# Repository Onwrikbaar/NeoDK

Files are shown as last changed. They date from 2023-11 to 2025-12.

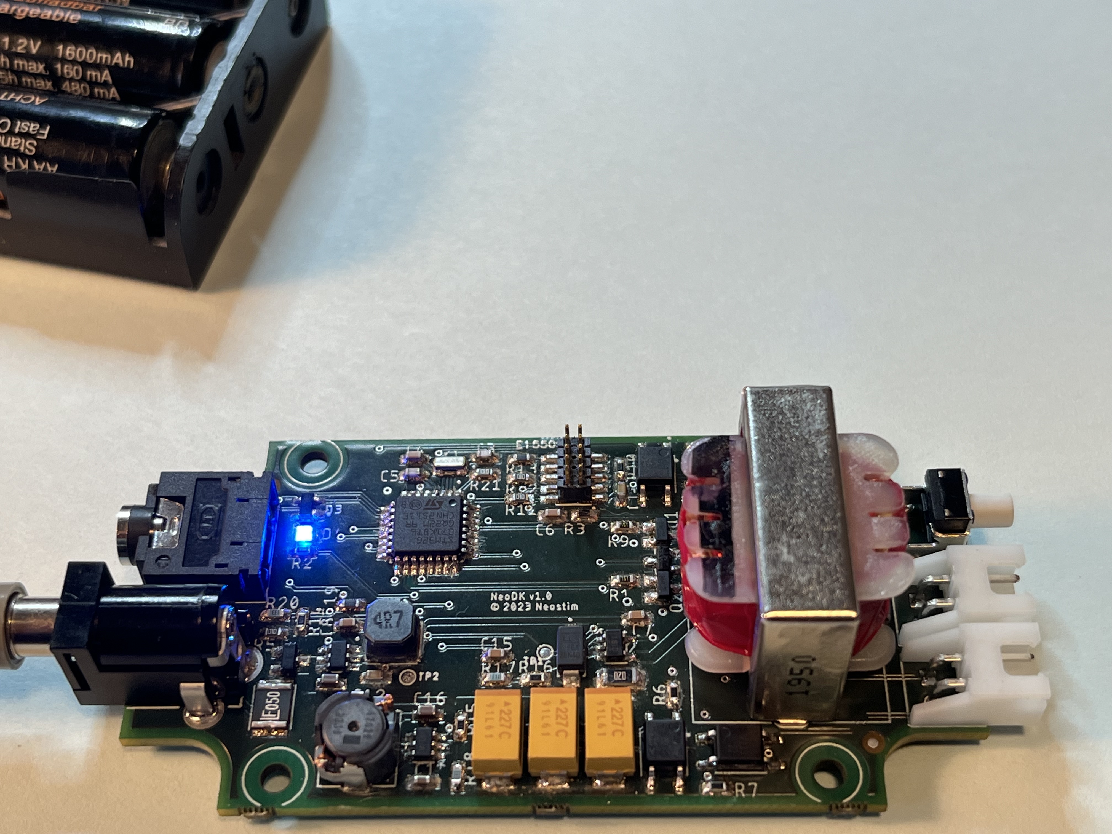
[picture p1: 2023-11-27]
pictures/PopulatedPCB.jpg

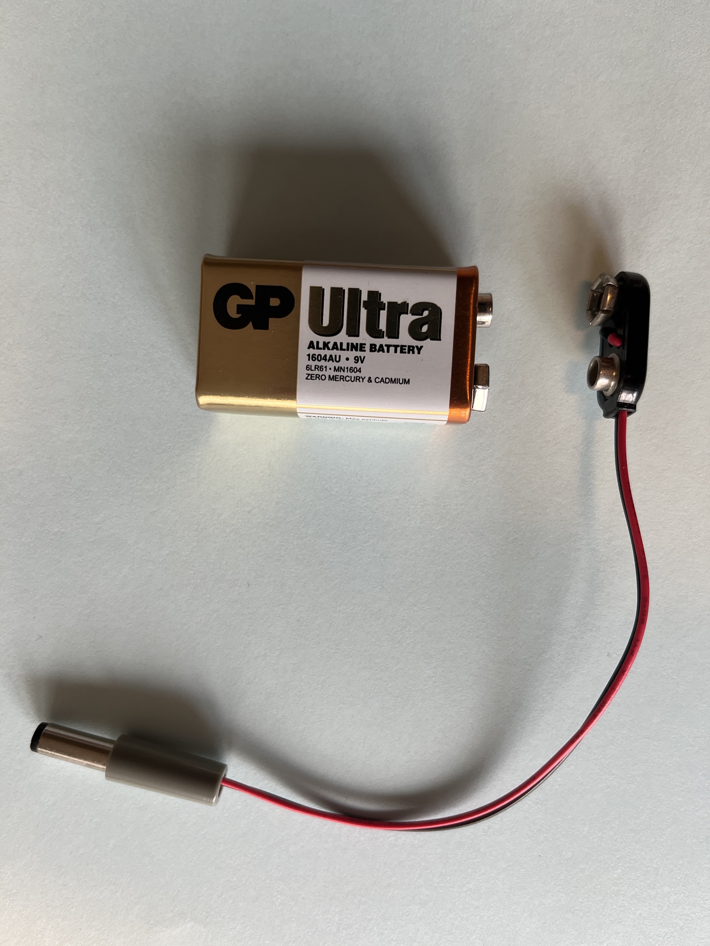
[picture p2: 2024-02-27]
pictures/BatteryCable.jpg

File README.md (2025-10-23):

# NeoDK
Advanced electrostimulation machine development kit.

## Overview
### What is it?
This project describes the design and implementation of a bare-bones, yet highly innovative and powerful, pulse-based electrostimulation device. Both its hardware and its firmware are open for modification and extension.

### Author
Discord: @Onwrikbaar<br/>
E: <onwrikbaar@hotmail.com>

### Status
This is a work in progress. The electronics are production-ready. The firmware is far from finished.

### Goals
1. The last quarter century, innovation in the e-stim realm has been virtually nonexistent, despite massive advances in electronics and cheap computing power. Currently available commercial devices are without exception channel-oriented and produce TENS-style waveforms. Most are horrendously energy-inefficient. The time has come to unlock the potential of a more capable architecture.
2. It is fairly easy for non-programmers to create, share and improve routines to be played on stereostim setups. Currently there is no way to achieve the same for pulse-based e-stim devices. This project aims to (eventually) bridge that gap.

### Disclaimer
NeoDK is experimental, recreational, educational hardware and software. It comes with absolutely no warranty of any kind. Its designs are free to use - under the conditions set forth in its [Licence](LICENSE.txt). Using the designs -in original or modified form- implies acceptance of any and all associated risks and liabilities.

### How to use NeoDK
- Use it entirely at your own risk.
- Keep any and all electrodes connected to this device placed below the waist.
- Always start out at low intensity, especially when using insertable electrodes.

### How NOT to use NeoDK
- Do not use it for anything safety-critical, medical, industrial, military, commercial, immoral, or illegal - it was not designed for any of that.
- Do not use it on anyone without explicit and informed consent.
- Do not use a so-called triphase cable with this device!

### Safety
NeoDK can generate potentially lethal voltages and currents on its outputs and on internal components, even when powered from a battery. The risks associated with building, testing and using this device can be reduced but not eliminated.

The NeoDK device is designed to stay within the IEC 60601-2-10 limits once its firmware is out of beta. However, these limits are not necessarily maintained when the supply voltage, circuit, components or accompanying firmware are changed in any way.

### Audience
This project is intended for experienced electronics hobbyists and professionals, who possess a keen understanding of the risks associated with electrostimulation and high-voltage circuitry, and who desire one or more of the following:
- e-stim sensations unattainable through conventional power boxes.
- a high-intensity remotely controllable e-stim device to incorporate into a multi-toy setup or home control system.
- a deeper understanding of advanced, energy-efficient electronic circuitry for pulse-based electrostimulation.
- an innovative yet compact, proven design to base one's own developments on.
- a pulse-based device that can store and play user-created routines (planned for 2026).

### Caveat
NeoDK is _NOT_ a ready-for-play e-stim box. It is a minimal viable design (MVD) of a powerful and highly efficient electrostimulation device that is not limited by 2-pole 'channels' or strictly TENS-like waveforms. Schematic and board CAD files are included, but to get a working device involves some (easy) soldering. To get more than the basic functionality requires programming in C, or being patient.

### How to get a working NeoDK
By far the easiest way to build NeoDK, is to order the SMD-populated PCB from JLCPCB (using the files in directory JLCPCB_prod) and buy the six through hole components separately. Soldering the through hole components onto the board is easy.

### Licensing
NeoDK's electronics and firmware can do things no commercially available e-stim box comes close to. If this appeals to you but you would like to have more features than NeoDK offers, by all means use NeoDK as the foundation for your own design - while observing this project's [Licence](LICENSE.txt). Regarding licensing for commercial / non-open source purposes, please contact the author.

### Why to start simple
"A complex system that works is invariably found to have evolved from a simple system that worked. A complex system designed from scratch never works and cannot be patched up to make it work. You have to start over with a working simple system." -- John Gall

## NeoDK in the media
Joanne's Reviews' always informative and entertaining YouTube [E-stim Livestreams](https://www.youtube.com/@JoannesReviews/streams) recently featured an [item about NeoDK](https://youtu.be/giEaDksRmh0?t=1460).

## Other OSHW electrostimulation projects
- [zc95](https://github.com/CrashOverride85/zc95). A feature-rich four channel machine.
- [FOC-Stim](https://github.com/diglet48/FOC-Stim). Highly innovative, quickly rendering stereostim obsolete.
- Noisy Cricket (soon to be published). An incredibly compact device primarily aimed at BDSM play.

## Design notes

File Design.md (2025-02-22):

# Design
## Functional design
### Requirements
1. Four monopolar symmetric biphasic outputs, no 'channels'.
2. Outputs are galvanically isolated from the low-voltage circuitry and the communication interface.
3. Sufficient output power to drive even the largest insertable metal electrodes with amazing intensity.
4. Very energy-efficient, so optionally battery-powered.
5. Controllable by externally/remotely running software.

### Electrical characteristics (preliminary)
- NeoDK outputs rectangular pulses with a maximum voltage of 100V across a 500 Ω load. Pulses can have either of the two polarities, so Vpp is 200V.
- Maximum pulse width is 200 µs.
- Maximum charge per pulse is 40 µC for a 500 Ω load.
- Maximum energy into a 500 Ω load is 4 mJ per pulse.
- Maximum pulse repetition rate is 200 Hz.
- Maximum dutycycle is 200 µs * 200 Hz * 100% = 4%.
- Maximum average output power into a 500 Ω load is 4 mJ * 200 Hz = 800 mW. This corresponds to a current of 40 mA RMS.
- Average current draw from the power supply or battery is less than 200 mA.

### Output configurations
The four biphasic unipolar outputs A, B, C and D can be switched under software control in the following nine ways (X-Y means current can flow from electrode X to electrode Y, or vice versa. X-YZ means current flows from electrode X to electrodes Y and Z simultaneously):
- A-B
- C-B
- AC-B
- A-D
- C-D
- AC-D
- A-BD
- C-BD
- AC-BD

Every single pulse can have either of the two polarities, and be directed to any of the nine different electrode configuration of 2, 3 or 4 electrodes, if so desired. This allows the creation of stimulation patterns that are perceived as moving across the skin or in 3D through the body.

## Electronic design
### The output transformer
- A supply voltage of about 10V must be stepped up by a factor of 10 to reach the desired output voltage of 100V. For this, we use a small audio impedance matching transformer. Since we only drive half of the (center-tapped) primary coil at a time, the ratio of the whole primary to the secondary needs to be 1:5.
- The transformer must have a power rating of around 800 mW (see electrical characteristics above).
- The maximum secondary current through a 500 Ω load is 100V/500 Ω = 0.2 A. The primary current is then 10 * 0.2 A = 2A. To limit the ohmic losses at this current, the DC-resistance of the primary should be at most 0.5 Ω.
- The transformer needs to have a bandwidth of at least a few kHz in order to handle the rectangular pulses well enough.

An off-the-shelf, cheap transformer that meets these criteria, is the Xicon 42TU200, which is carried by [Mouser Electronics](https://www.mouser.com).

### Switch matrix
The output voltage of the transformer is distributed to the four electrodes through a 4-node switch matrix consisting of opto-triacs (aka photo-triacs or triac output optocouplers).

### Buffer capacitor
When the device is powered from a battery that cannot immediately deliver the required primary current, a charge buffer is needed to help supply the output stage. For this, we use three low-ESR 220 µF 16V tantalum capacitors in parallel. At the maximum primary voltage of 10V, these capacitors together hold 6.6 mC of charge, representing 33 mJ of energy.

### Snubber
Stray inductance of the transformer causes inductive spikes every time the primary current is switched off. These spikes must be suppressed in order to prevent destruction of the MOSFETs that switch the transformer's primary. This is accomplished by 'shorting' the spikes to the primary voltage rail when they exceed a critical value. This way part of the energy stored in the transformer's inductance is dumped back into the capacitors.

### Primary current sensing
The primary current is measured on the high side, by means of a 20 mΩ shunt resistor and a x20 current sense amplifier. The output of the current sense amplifier is fed to an ADC input of the microcontroller. This way, the maximum primary current that can be reliably measured is 3.3V / (20 * 20 mΩ) = 8.25 A.

### Primary voltage sensing
The primary voltage is measured through a ÷4 voltage divider connected to an ADC input of the microcontroller. This way, the maximum primary voltage that can be reliably measured is 4 * 3.3V = 13.2V.

### Primary voltage control
The primary voltage is regulated by a (switching) buck converter, which is controlled through a DAC output of the microcontroller. This method ensures very efficient use of the battery capacity as well as negligible heat generation. Due to the buck's maximum under-voltage lockout threshold and the voltage drop across the resettable fuse, the device requires a minimum supply voltage of 6V for correct operation.

### Microcontroller
The STM32G071 is an affordable 32-bit microcontroller with an ARM Cortex M0+ core, 128 KB flash and 36 KB RAM. Its maximum clock speed is 64 MHz, which yields considerably more processing power than required to run the application.
- [datasheet](https://www.st.com/resource/en/datasheet/stm32g071c8.pdf)
- [reference manual](https://www.st.com/resource/en/reference_manual/rm0444-stm32g0x1-advanced-armbased-32bit-mcus-stmicroelectronics.pdf)

### Recommended power source
For safety, it is best to power NeoDK from a battery, like a 3S (nominally 11.1V) Li-ion battery pack. When using a mains voltage adapter ('wall wart') instead, make sure it is doubly insulated and meets all applicable safety standards for your region. If you happen to own an Estim Systems 2B power box, you can use its 12V mains adapter for NeoDK too.

### Serial communications interface
The device is controlled through a standard serial UART interface using 3.3V TTL signal levels at 115200 bps. Suitable USB-to-serial cables (3.3V TTL, Tip=Tx, Ring=Rx, Sleeve=GND) are readily available from various sources, like Aliexpress, for about €10 including shipping.

## Firmware
The device's on-board control program (aka firmware) consists of a collection of collaborating hierarchical state machines. The firmware is event-driven and 100% nonblocking.

### Structure
Conceptually, the firmware consists of two layers:
1. The hardware-dependent part, called the Board Support Package (BSP), which implements the _mechanisms_. This is the only module that needs to be changed when porting the application to a different processor.
2. The hardware-independent application logic, implementing the _policies_.

### About the code
- All C modules, with the exception of the BSP, are less than 500 lines long.
- Functions are short, or have low cyclomatic complexity.
- Functions are _pure_ whenever possible.
- There are no global variables, preventing unwanted coupling between modules as well as violation of invariants.
- Most 'plumbing' is done through dependency injection.
- Object types are opaque where possible.

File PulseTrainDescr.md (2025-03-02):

# The Pulse Train Descriptor
## Purpose
Pulse train descriptors are a means to efficiently stream in real time electrostimulation patterns from a phone or computer to a power box. A pulse train descriptor specifies the output stage, polarity, electrode configuration, timing, and intensity of a sequence of pulses.
## Structure
A pulse train descriptor consists of up to 11 members, occupying up to 16 bytes. Multi-byte members are stored little-Endian.
```
    uint8_t  meta;                  // Type, version, flags, etc., for correct interpretation of this descriptor.
    uint8_t  sequence_number;       // For diagnostics. Wraps around to 0 after 255.
    uint8_t  phase;                 // Bits 2..1 select 1 of 4 biphasic output stages. Bit 0 is the selected stage's polarity.
    uint8_t  pulse_width_µs;        // The duration of one pulse [µs].
    uint32_t start_time_µs;         // When this burst should begin, relative to the start of the stream.
    uint8_t  electrode_set[2];      // The (max 8) electrodes connected to each of the two output phases of the selected output stage.
    uint16_t nr_of_pulses;          // Length of this burst.
    uint8_t  pace_¼ms;              // [0.25 ms] time between the start of consecutive pulses.
    uint8_t  amplitude;             // Voltage, current or power, in units of 1/255 of the set maximum.
    // The following members [-128..127] are applied after each pulse of this train.
    int8_t   delta_pulse_width_¼µs; // [0.25 µs]. Changes the duration of the pulses.
    int8_t   delta_pace_µs;         // [µs]. Modifies the time between pulses.
```
## Descriptor size and interpretation
- If `delta_pace_µs` = 0, it may be omitted.
- If `delta_pace_µs` = 0 and `delta_pulse_width_¼µs` = 0, they may both be omitted.
- `amplitude` = 0 means 'the same amplitude as the previous descriptor', or 'amplitude is set through other means'. It does _not_ set the output level to 0.
- If `delta_pace_µs` = 0 and `delta_pulse_width_¼µs` = 0 and `amplitude` = 0, all three may be omitted.
- If `nr_of_pulses` = 1, `pace_¼ms` is ignored and may be omitted if `amplitude`, `delta_pulse_width_¼µs` and `delta_pace_µs` are omitted. In this case `nr_of_pulses` may be omitted as well and will be taken to be 1.
- For hardwired output stages (i.e. without any sort of switch matrix between the transformers and the electrodes) `electrode_set` is not used. It may be omitted if all the members following it are omitted.
- Summarising the above, the minimal pulse train descriptor contains only the first 5 members and is 8 bytes in size.
- `meta` must be set to 0x00, for now.
- Bits 7..3 of `phase` are reserved for future use.
## Example: generating TENS-style pulses
1. Send a pulse train, followed by the same pulse train time-shifted and with opposite phase. For instance:<br/>
`Pt 1: t=  0 µs, ec=0x5<>0xa, phase=0, np=50, pace=80 ¼ms, amp=0, pw=130 µs, Δ=0 ¼µs`<br/>
`Pt 2: t=180 µs, ec=0x5<>0xa, phase=1, np=50, pace=80 ¼ms, amp=0, pw=130 µs, Δ=0 ¼µs`<br/>
The time shift needs to be at least the pulse width plus the minimum dead time.
2. Send the command to execute the received pulse trains. This implies that the firmware be able to buffer several pulse train descriptors.

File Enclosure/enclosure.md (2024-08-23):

The NeoDK PCB was designed to fit [Gainta handheld enclosure G404](https://www.gainta.com/en/g404.html), which can be obtained [from TME](https://www.tme.eu/en/details/g404/enclosures-with-panel/gainta/), Farnell (ordercode 1526729) and Newark (part no. 74M2302).

Discord user @edger477 created CAD files to 3D-print nice front and back panels. The files can be found in this directory.

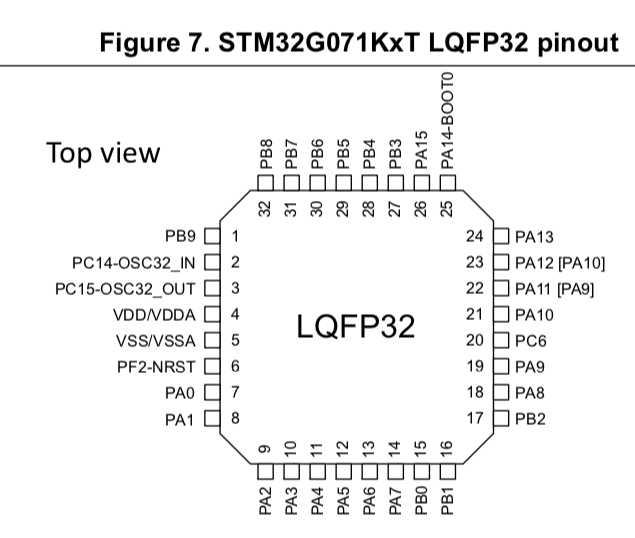
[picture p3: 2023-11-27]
pictures/MCU_Pinout.png

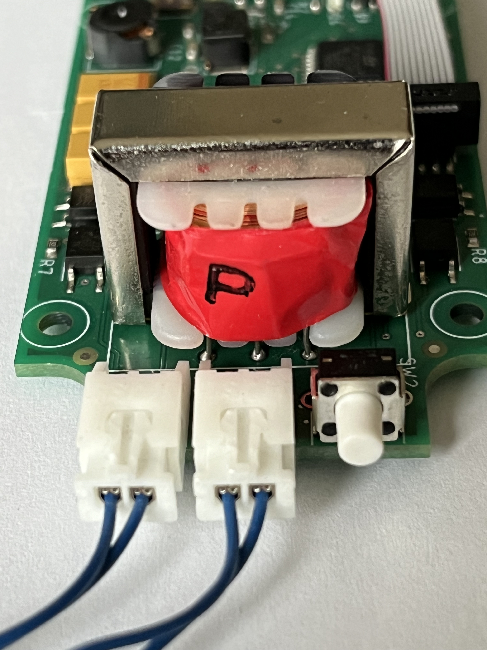
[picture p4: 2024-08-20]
pictures/TrafoOrient.jpg

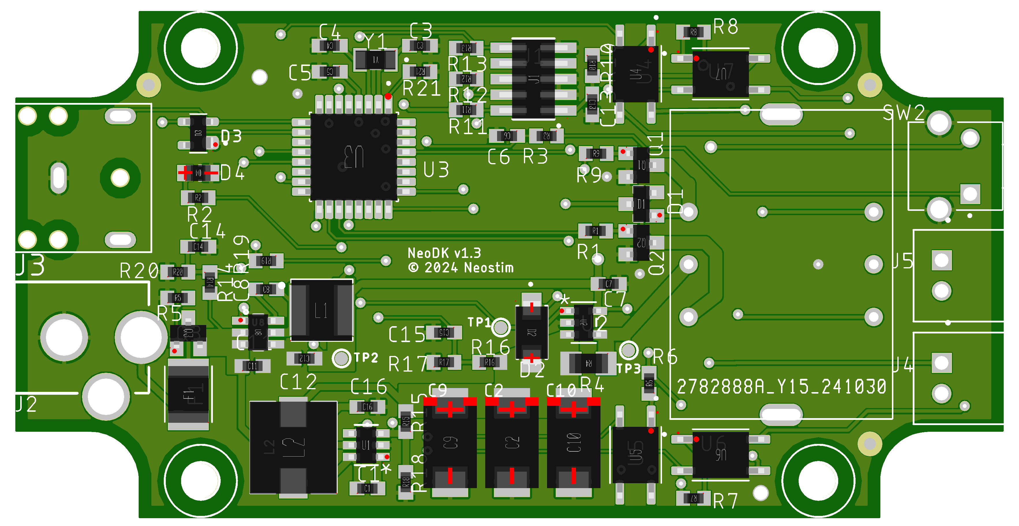
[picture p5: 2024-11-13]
pictures/SMD_layout.png

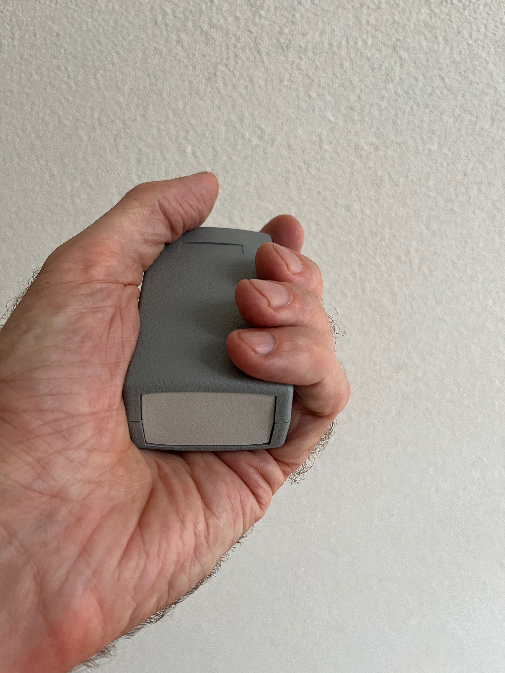
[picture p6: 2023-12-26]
pictures/BoxSize.jpg

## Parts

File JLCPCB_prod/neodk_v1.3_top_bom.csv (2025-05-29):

Comment | Designator | Footprint | LCSC Part #
0.02 | R4 | R1206
1k5 | R3 R13 | R0603
VLS5045EX-4R7M | L1 | IND_VLS5045EX-4R7M
6.8p | C3 C4 | C0603
10u 25V | C11 C16 | C0603 | CL10A106MA8NRNC
13k | R17 R18 R20 | R0603
22u | C12 C13 | C0603
X1A0001410003 | Y1 | SMD3215-2P
39k | R14 R16 | R0603
42.2k | R19 | R0603
CLF7045NIT-330M-D | L2 | IND_CLF7045NIT-330M-D | C138629
100k | R5 R11 R12 R21 | R0603
100n | C5 C6 C7 C8 C14 C15 | C0603
115k | R15 | R0603
T491X227K016AT | C2 C9 C10 | SMC_D
300 | R1 R2 R6 R7 R8 R9 R10 | R0603
470n | C1 | C0603
AP63203WU-7 | U8 | SOT23-6
BAV23CLT1G | D1 | SOT23
INA180A1IDBVR | U2 | DBV5
IRLML6344TRPBF | Q1 Q2 | SOT23 | C53550
1812L050/30PR | F1 | 1812 | C151168
PMV50EPEAR | Q3 | SOT23 | C478012
PRTR5V0U2X | D3 | SOT-143
SGM61410XN6G(TOKMAS) | U1 | SOT-23-6_SNC
SMAJ13A | D2 | SMA
HL-PC-2012H392BC-L | D4 | 0805 | C497943
STM32G071KBT6 | U3 | QFP80P900X900X160-32N
20021121-00010T4LF | J1 | 20021121-00010T4LF
TLP268J | U4 U5 U6 U7 | SOP254P675X240-4N

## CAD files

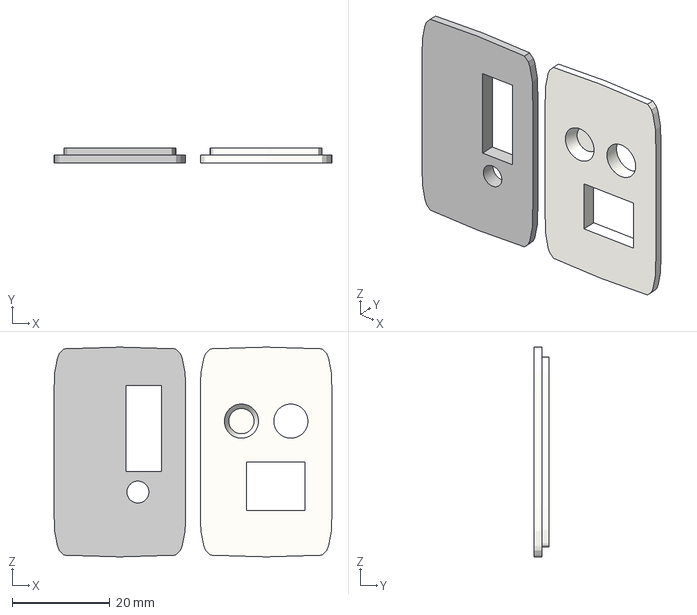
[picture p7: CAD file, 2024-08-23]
Enclosure/NeoDK-Covers v5.3mf
57.0 x 3.00 x 43.0 mm
Cover-Front
Cover-Rear

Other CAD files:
Enclosure/NeoDK-Case v9.f3d
Enclosure/NeoDK-Covers v5.f3d

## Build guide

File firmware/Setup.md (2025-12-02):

## Updating the firmware without using a debugging probe
1. Download and install STM's free [STM32CubeProgrammer](https://www.st.com/en/development-tools/stm32cubeprog.html) programming tool.
2. Get [neodk_g071.hex](https://github.com/Onwrikbaar/NeoDK/tree/main/firmware/build/neodk_g071.hex). Click the "Download raw file" icon to download.
3. Connect NeoDK to a computer using a USB-to-3.5mm-TRS-serial cable. Suitable cables (3.3V TTL, Tip=Tx, Ring=Rx, Sleeve=GND) are readily available from various sources, like Aliexpress, for about €10 including shipping.
4. Press and hold the pushbutton on NeoDK while switching on its power (or connecting the battery). This puts NeoDK in bootloader mode. Release the button.
5. Open a terminal window and execute the following on the command line:<br/>
&nbsp;&nbsp;`STM32_Programmer_CLI -c port=/dev/tty.usbserial-0001 -w neodk_g071.hex -v`<br/>
Specify the COM port that corresponds to your USB-serial cable (for instance `COM7` on Windows), in place of `/dev/tty.usbserial-0001`.<br/>
A power cycle starts the firmware; the blue LED should light up and the box is ready for use.

## Controlling NeoDK from a computer
1. Connect NeoDK to a computer using a USB-to-3.5mm-TRS-serial cable (3.3V TTL, Tip=Tx, Ring=Rx, Sleeve=GND).
2. Open a Chrome, Edge or Opera browser window and point it to [@edger477's colorful UI](https://edger477.github.io/NeoDK/UI).

## Developing code for NeoDK
### Debugging probe
A suitable probe is the Segger JLink or Segger JLink EDU. Other probes supporting the SWD interface will work too.

### Compiler
1. Download and install the [Arm GNU Toolchain](https://developer.arm.com/Tools%20and%20Software/GNU%20Toolchain) for bare metal targets.
2. Edit [Makefile.posix](toolchain/gcc/Makefile.posix) or [Makefile.windows](toolchain/gcc/Makefile.windows) (depending on your operating system) to set three environment variables to their appropriate values. Alternatively, they can be set in the startup file for your command line interface.

### STM's low-level code library
1. Download and install [STM32Cube for STM32G0 series](https://www.st.com/en/embedded-software/stm32cubeg0.html).
2. In your home directory, create a softlink to directory 'STM32Cube' of the just installed tree.

### SEGGER J-Link software
1. Download and install [Segger J-Link](https://www.segger.com/downloads/jlink/).
2. In the just installed Segger directory tree, find file JLink_V792k/Samples/RTT/SEGGER_RTT_V792k.tgz and unpack it in place.
3. In your home directory, create a softlink named 'SEGGER_RTT' to directory 'JLink_V792k/Samples/RTT/SEGGER_RTT_V792k/RTT' of the just installed tree.

### Checking your installation
&nbsp;&nbsp;`cd NeoDK/firmware/neodk`<br/>
In this directory ('firmware'), at the command prompt type

&nbsp;&nbsp;`make`

This should compile the demo code without errors and create file 'neodk_g071.hex' (and a few others) in directory 'build'.

### Updating the firmware using Segger JLink
Connect the JLink to a USB port of your computer, and to the 10-pin SWD header on the NeoDK board.
On the commandline type<br/>
&nbsp;&nbsp;`cd firmware/neodk`<br/>
&nbsp;&nbsp;`JLinkExe -device stm32g071kb -if SWD -speed 4000 -autoconnect 1`<br>
(On Windows, the command is probably called JLink rather than JLinkExe)<br>
At the JLink prompt, type<br>
&nbsp;&nbsp;`loadfile build/neodk_g071.hex`<br>
&nbsp;&nbsp;`r`<br>
&nbsp;&nbsp;`g`<br>
NeoDK's blue LED should now light up.
In another window, open a Segger console<br>
&nbsp;&nbsp;`JLinkRTTClient`<br>
This should now show output from NeoDK.<br>
In the JLinkRTTClient window, type<br>
&nbsp;&nbsp;`/?`<br>
to see a list of available NeoDK interactive commands.

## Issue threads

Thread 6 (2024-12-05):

JLCPCB DFM Issue: C9, C2 placed with wrong polarity

calotlea, 2024-12-05:
I just triggered a build with the latest JLCPCB files, the CPL file may need a 180 degree rotation for C9 and C2. See attached.

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

Onwrikbaar, 2024-12-05:
This is a JLC layout viewer anomaly that I've seen before. All three capacitors have the same rotation in the CPL file. On ordering JLC will catch the error and either inquire about it or tacitly correct it.

Thank you for reporting it!

Closed 2024-12-05.

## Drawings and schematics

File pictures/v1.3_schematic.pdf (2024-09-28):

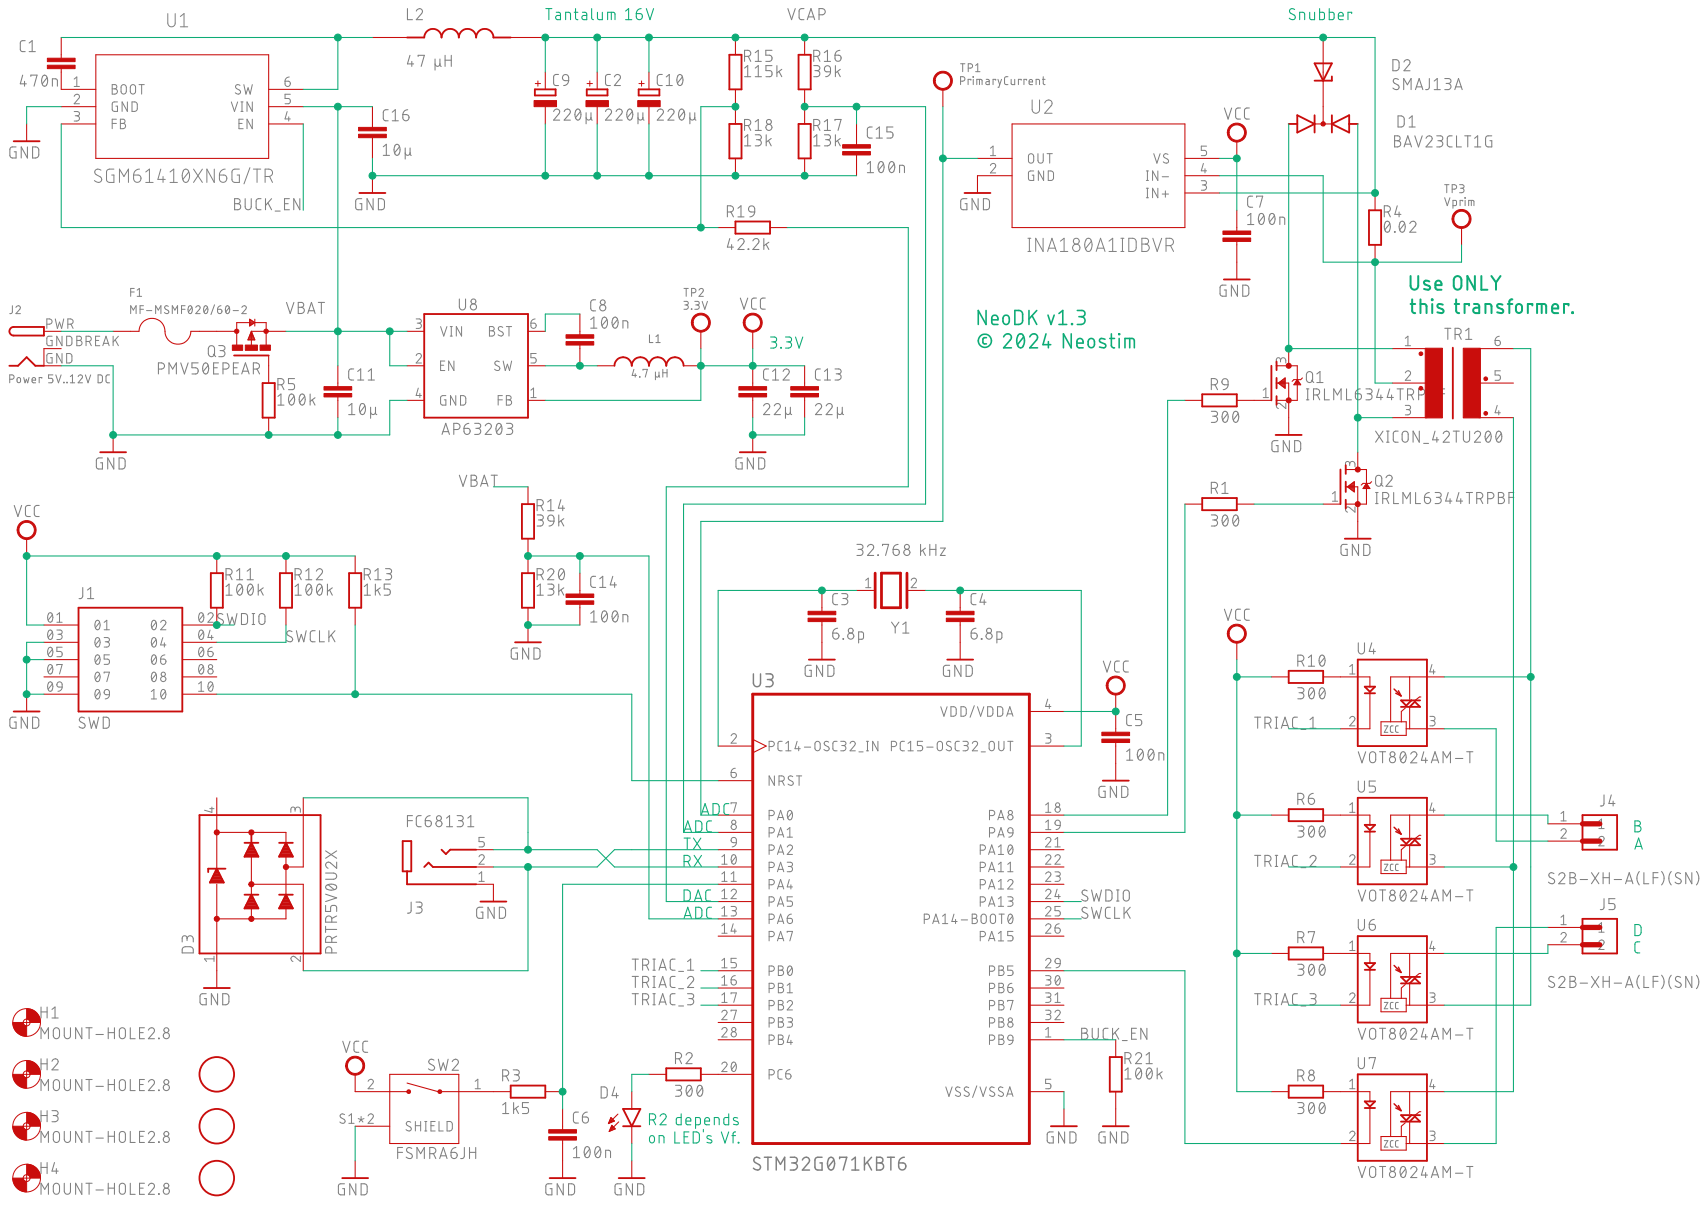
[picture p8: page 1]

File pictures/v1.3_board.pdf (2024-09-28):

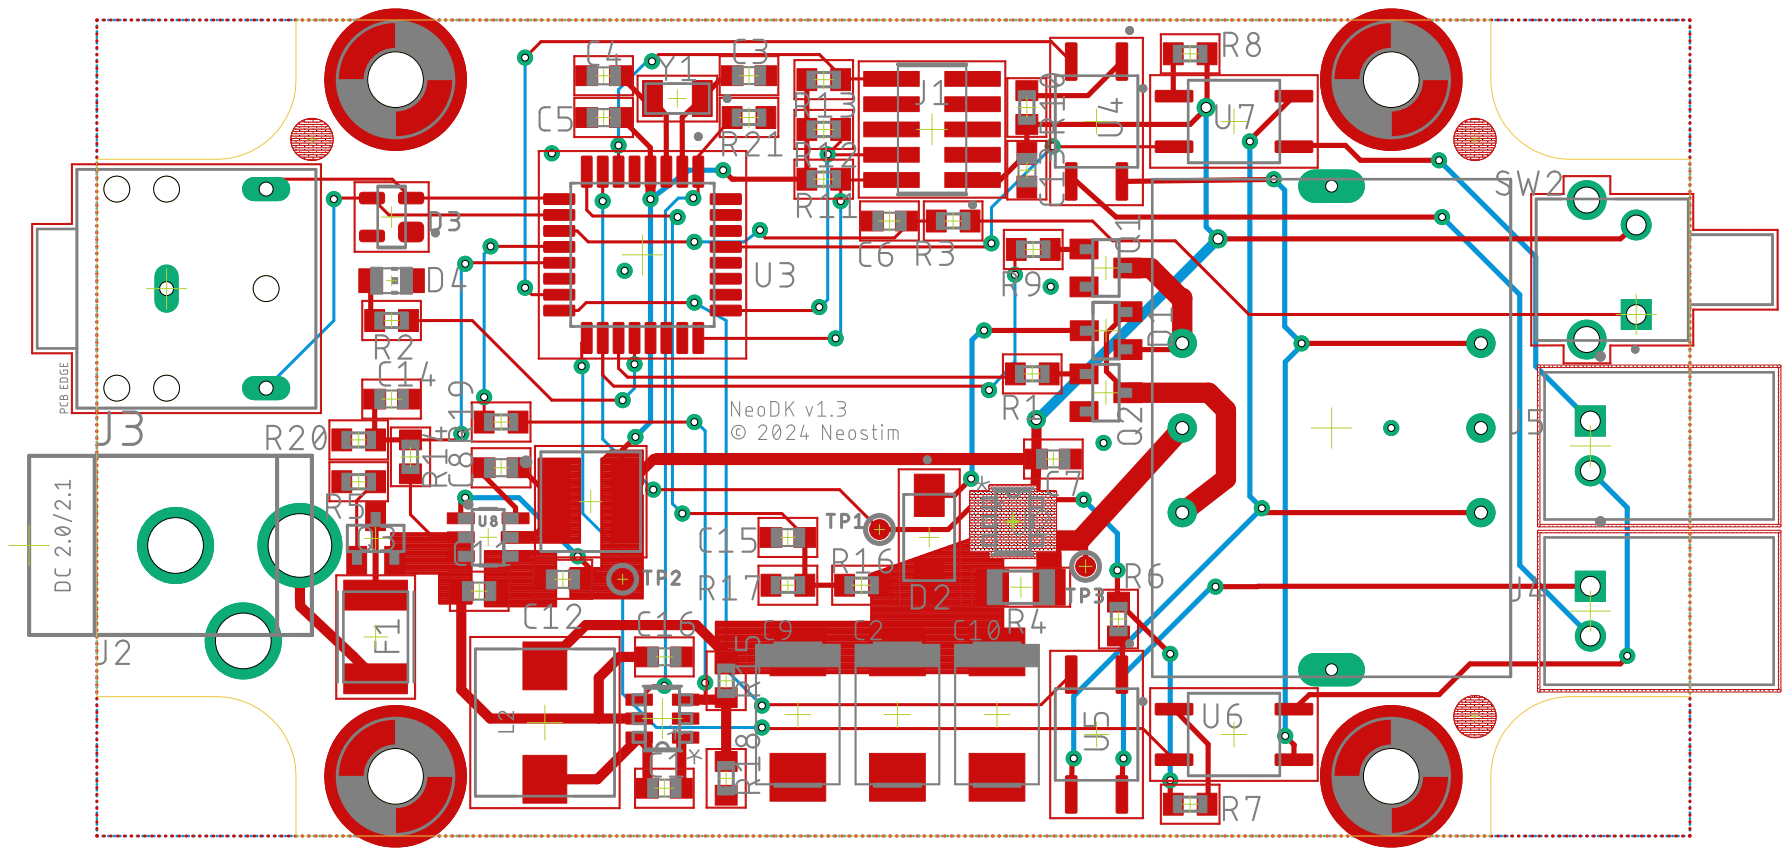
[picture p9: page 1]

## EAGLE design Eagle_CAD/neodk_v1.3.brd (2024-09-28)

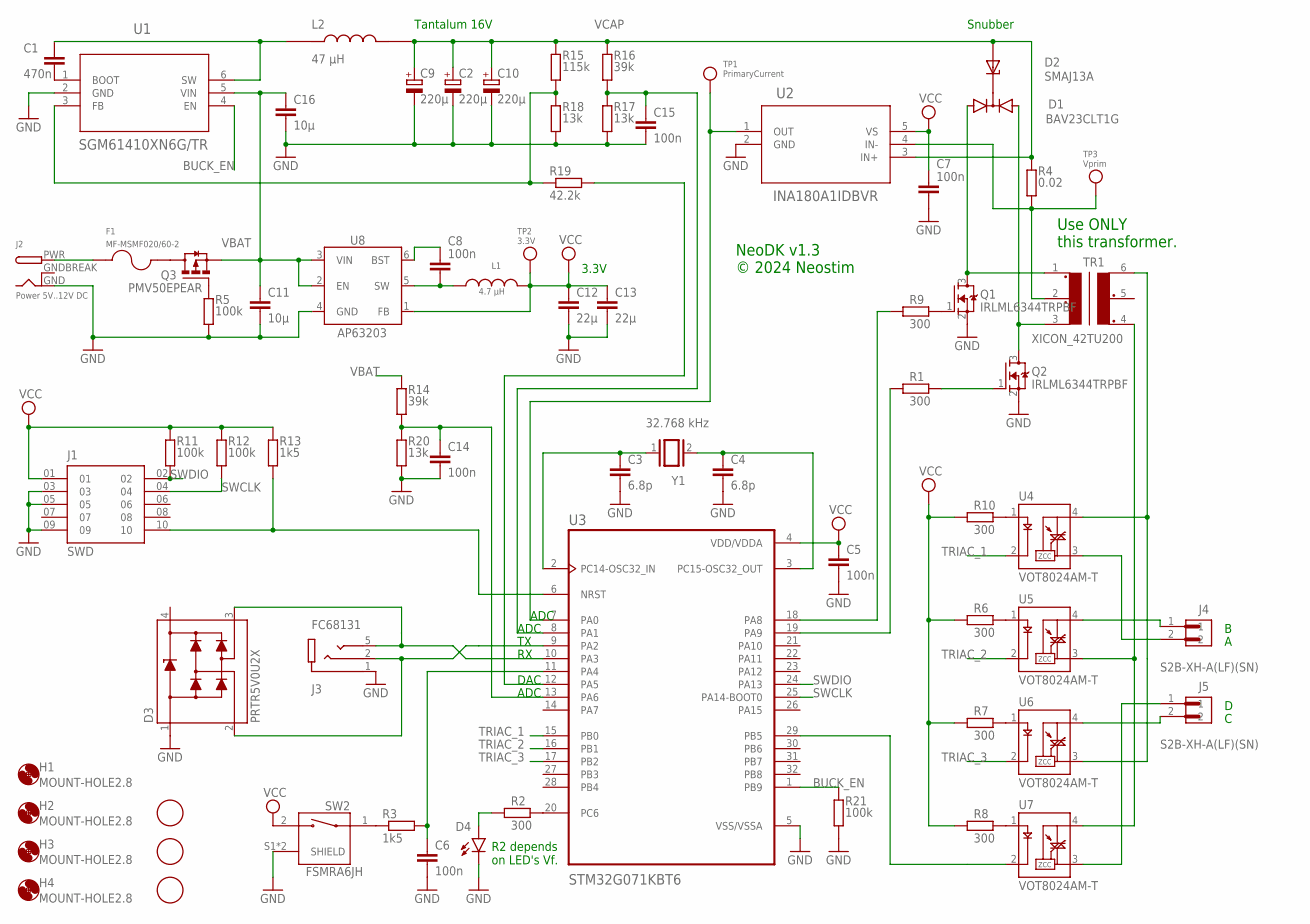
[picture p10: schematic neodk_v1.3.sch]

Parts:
C1: 470n; C0603
C2, C9, C10: 220µ; SMC_D
C3, C4: 6.8p; C0603
C5, C6, C7, C8, C14, C15: 100n; C0603
C11, C16: 10µ; C0603
C12, C13: 22µ; C0603
D1: BAV23CLT1G; SOT23
D2: SMAJ13A; DIOM4325X250N
D3: PRTR5V0U2X; SOT190P230X110-4N
D4: LEDCHIP-LED0805; CHIP-LED0805
F1: MF-MSMF020/60-2; FUSER_MF-MSMF020/60-2
FID1, FID2, FID3: FIDUCIAL; FIDUCIAL_1MM
H1, H2, H3, H4: MOUNT-HOLE2.8; 2,8
J1: SWD; SAMTEC_FTSH-105-XX-X-DV
J2: Power 5V..12V DC; DCJACK_2MM_PTH
J3: FC68131; CLIFF_FC68131
J4, J5: S2B-XH-A(LF)(SN); JST_S2B-XH-A(LF)(SN)
L1: 4.7 µH; IND_VLS5045EX-4R7M
L2: 47 µH; IND_CLF7045NIT-470M-D
Q1, Q2: IRLML6344TRPBF; SOT23
Q3: PMV50EPEAR; SOT23
R1, R2, R6, R7, R8, R9, R10: 300; R0603
R3, R13: 1k5; R0603
R4: 0.02; R1206
R5, R11, R12, R21: 100k; R0603
R14, R16: 39k; R0603
R15: 115k; R0603
R17, R18, R20: 13k; R0603
R19: 42.2k; R0603
SW2: FSMRA6JH; TE_FSMRA6JH
TP1: PrimaryCurrent; TESTPOINT_ROUND_1MM
TP2: 3.3V; TESTPOINT_ROUND_1MM
TP3: Vprim; TESTPOINT_ROUND_1MM
TR1: XICON_42TU200; 42TUXXX
U1: SGM61410XN6G/TR; SOT-23-6_SNC
U2: INA180A1IDBVR; DBV5
U3: STM32G071KBT6; QFP80P900X900X160-32N
U4, U5, U6, U7: VOT8024AM-T; SOP254P675X240-4N
U8: AP63203; SOT23-6
Y1: 32.768 kHz; XTAL_NX3215SA-32.768K-STD-MUA-8

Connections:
BTN_OUT1: C6.1, R3.2, U3.11 (PA4)
BUCK_EN: R21.2, U1.4 (EN), U3.1 (PB9)
CSA_OUT: TP1.P$1, U2.1 (OUT), U3.7 (PA0)
GND: C2.-, C3.2, C4.2, C5.2, C6.2, C7.2, C9.-, C10.-, C11.2, C12.2, C13.2, C14.2, C15.2, C16.2, D3.1 (GND), D4.C, J1.03, J1.05, J1.09, J2.GND, J3.1 (SLEEVE), Q1.2 (S), Q2.2 (S), R5.1, R17.1, R18.1, R20.1, R21.1, SW2.S1 (SHIELD), SW2.S2 (SHIELD), U1.2 (GND), U2.2 (GND), U3.5 (VSS/VSSA), U8.4 (GND)
GNDBREAK: J2.GNDBREAK
unnamed: D1.3 (C), D2.C
unnamed: R3.1, SW2.1
unnamed: D1.1 (A1), Q1.3 (D), TR1.1
unnamed: D1.2 (A2), Q2.3 (D), TR1.3
unnamed: Q1.1 (G), R9.2
unnamed: Q2.1 (G), R1.2
unnamed: R2.2, U3.20 (PC6)
unnamed: D4.A, R2.1
unnamed: R4.1, TP3.P$1, TR1.2, U2.4 (IN-)
unnamed: R10.1, U4.1 (A)
unnamed: R6.1, U5.1 (A)
unnamed: R7.1, U6.1 (A)
unnamed: J4.1, U5.4 (MT2)
unnamed: R8.1, U7.1 (A)
unnamed: R1.1, U3.19 (PA9)
unnamed: U3.29 (PB5), U7.2 (C)
unnamed: J5.2, U6.4 (MT2)
unnamed: TR1.4, U5.3 (MT1), U7.4 (MT2)
unnamed: R9.1, U3.18 (PA8)
unnamed: TR1.6, U4.4 (MT2), U6.3 (MT1)
unnamed: J4.2, U4.3 (MT1)
unnamed: J5.1, U7.3 (MT1)
unnamed: C4.1, U3.3 (PC15-OSC32_OUT), Y1.2
unnamed: C3.1, U3.2 (PC14-OSC32_IN), Y1.1
unnamed: C8.2, L1.1, U8.5 (SW)
unnamed: D3.3 (I/O_2), J3.5 (TIP), U3.10 (PA3)
unnamed: F1.1, J2.PWR
unnamed: D3.2 (I/O_1), J3.2 (RING), U3.9 (PA2)
unnamed: F1.2, Q3.3 (D)
unnamed: Q3.1 (G), R5.2
unnamed: C1.1, L2.1, U1.6 (SW)
unnamed: C1.2, U1.1 (BOOT)
unnamed: C14.1, R14.1, R20.2, U3.13 (PA6)
unnamed: C8.1, U8.6 (BST)
unnamed: R15.1, R18.2, R19.1, U1.3 (FB)
unnamed: R19.2, U3.12 (PA5)
unnamed: J1.10, R13.1, U3.6 (NRST)
SWCLK: J1.04, R12.1, U3.25 (PA14-BOOT0)
SWDIO: J1.02, R11.1, U3.24 (PA13)
TRIAC_1: U3.15 (PB0), U4.2 (C)
TRIAC_2: U3.16 (PB1), U5.2 (C)
TRIAC_3: U3.17 (PB2), U6.2 (C)
VBAT: C11.1, C16.1, Q3.2 (S), R14.2, U1.5 (VIN), U8.2 (EN), U8.3 (VIN)
VCAP: C2.+, C9.+, C10.+, D2.A, L2.2, R4.2, R15.2, R16.2, U2.3 (IN+)
VCC: C5.1, C7.1, C12.1, C13.1, J1.01, L1.2, R6.2, R7.2, R8.2, R10.2, R11.2, R12.2, R13.2, SW2.2, TP2.P$1, U2.5 (VS), U3.4 (VDD/VDDA), U8.1 (FB)
VC_DIV4: C15.1, R16.1, R17.2, U3.8 (PA1)

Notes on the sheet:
Tantalum 16V
3.3V
DAC
Snubber
Use ONLY this transformer.
NeoDK v1.3 © 2024 Neostim
ADC
R2 depends on LED's Vf.

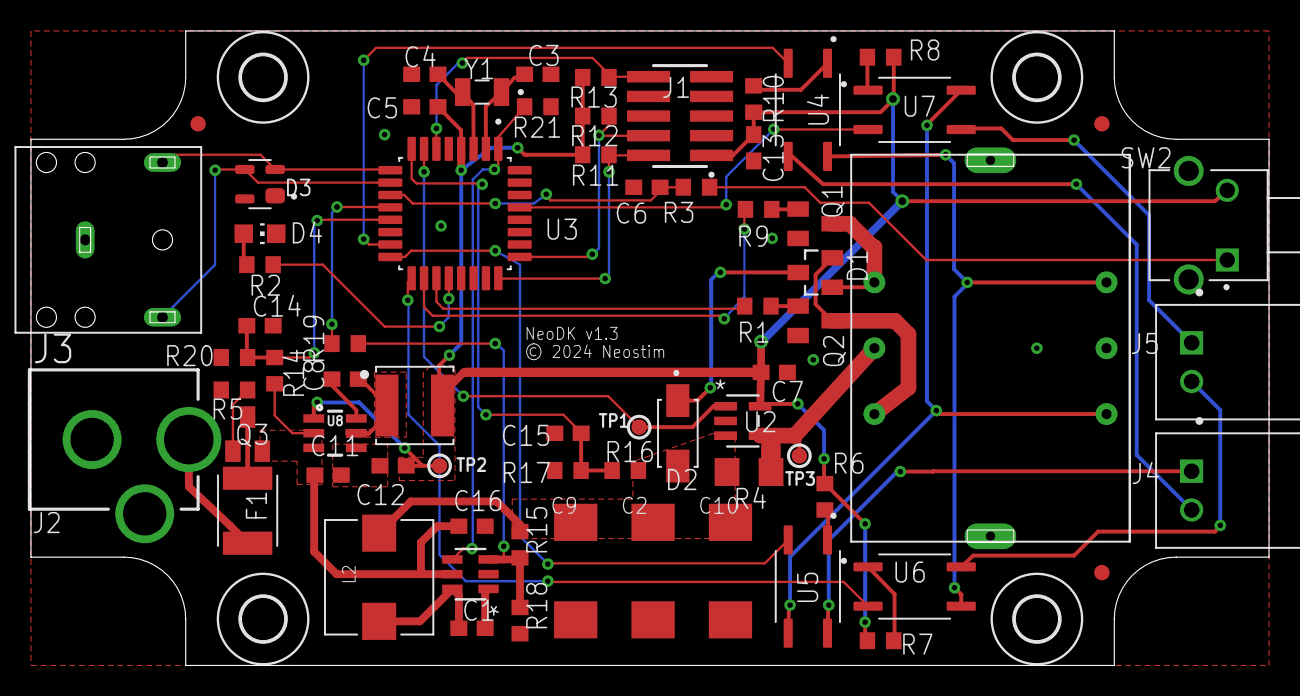
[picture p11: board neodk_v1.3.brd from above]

Board: 2 copper layers, 80.0 x 41.0 mm, 73 parts (0 on the bottom side), 50 nets.

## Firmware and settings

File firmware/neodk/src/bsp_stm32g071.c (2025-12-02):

/*
 *  bsp_stm32g071.c
 *
 *  NOTICE (do not remove):
 *      This file is part of project NeoDK (https://github.com/Onwrikbaar/NeoDK).
 *      See https://github.com/Onwrikbaar/NeoDK/blob/main/LICENSE.txt for full license details.
 *
 *  Created on: 20 Oct 2023
 *      Author: mark
 *   Copyright  2023..2026 Neostim™
 */

#include <limits.h>
#include <string.h>

#include "stm32g0xx_hal_rcc.h"
#include "stm32g0xx_hal_pwr.h"
#include "stm32g0xx_ll_system.h"
#include "stm32g0xx_ll_gpio.h"
#include "stm32g0xx_ll_exti.h"
#include "stm32g0xx_ll_tim.h"
#include "stm32g0xx_ll_dac.h"
#include "stm32g0xx_ll_adc.h"
#include "stm32g0xx_ll_dma.h"

#include "bsp_dbg.h"
#include "app_event.h"

// This module implements:
#include "bsp_mao.h"
#include "bsp_app.h"


#define ADC_GPIO_PORT           GPIOA
#define TRF_CURR_SENSE_PIN      LL_GPIO_PIN_0   // ADC_IN0.
#define CAP_VOLT_SENSE_PIN      LL_GPIO_PIN_1   // ADC_IN1.
#define BAT_VOLT_SENSE_PIN      LL_GPIO_PIN_6   // ADC_IN6.

#define DAC_GPIO_PORT           GPIOA
#define VCAP_BUCK_CTRL_PIN      LL_GPIO_PIN_5   // DAC1_OUT2.

#define PUSHBUTTON_PORT         GPIOA
#define PUSHBUTTON_PIN          LL_GPIO_PIN_4   // Digital in with pulldown.

#define MOSFET_GPIO_PORT        GPIOA
#define MOSFET_1_PIN            LL_GPIO_PIN_8   // Digital out, push-pull.
#define MOSFET_2_PIN            LL_GPIO_PIN_9   // Digital out, push-pull.

#define TRIAC_GPIO_PORT         GPIOB
#define TRIAC_1_PIN             LL_GPIO_PIN_0   // Digital out, open drain.
#define TRIAC_2_PIN             LL_GPIO_PIN_1   // Digital out, open drain.
#define TRIAC_3_PIN             LL_GPIO_PIN_2   // Digital out, open drain.
#define TRIAC_4_PIN             LL_GPIO_PIN_5   // Digital out, open drain.
#define ALL_TRIAC_PINS          (TRIAC_1_PIN | TRIAC_2_PIN | TRIAC_3_PIN | TRIAC_4_PIN)

#define BUCK_GPIO_PORT          GPIOB
#define BUCK_ENABLE_PIN         LL_GPIO_PIN_9   // Digital out, push-pull.

#define LED_GPIO_PORT           GPIOC
#define LED_1_PIN               LL_GPIO_PIN_6   // The on-board LED.

#define ALL_TRIACS_OFF          0x00

// #define ADC_TIMER_FREQ_Hz        100000UL
#define SEQUENCER_CLOCK_FREQ_Hz 1000000UL
#define PULSE_TIMER_FREQ_Hz     1000000UL
#define APP_TIMER_FREQ_Hz       2000000UL
#define TICKS_PER_MICROSECOND   (APP_TIMER_FREQ_Hz / 1000000UL)


typedef struct {
    // The following members get set only once.
    void (*app_timer_handler)(void *, uint64_t);
    void *app_timer_target;
    uint32_t clock_ticks_per_app_timer_tick;
    Selector button_sel;
    EventQueue *delegate;
    // The following members may get updated regularly.
    uint8_t critical_section_level;
    uint16_t volatile adc_1_samples[3];         // Must match the number of ADC1 ranks.
    uint16_t V_prim_mV;
    uint16_t volatile pulse_seqnr;
    Burst volatile next_burst;
    // Deltas next_deltas;
    uint8_t volatile elcon_available;
} BSP;

// The interrupt request priorities, from high to low.
enum {  // STM32G0xx MCUs have 4 interrupt priority levels.
    IRQ_PRIO_PULSE, IRQ_PRIO_SEQ_CLOCK = IRQ_PRIO_PULSE,
    IRQ_PRIO_ADC_DMA, IRQ_PRIO_SYSTICK = IRQ_PRIO_ADC_DMA,
    IRQ_PRIO_USART, IRQ_PRIO_APP_TIMER = IRQ_PRIO_USART,
    IRQ_PRIO_ADC1, IRQ_PRIO_EXTI = IRQ_PRIO_ADC1
};

// Ensure the following three consts refer to the same timer.
static TIM_TypeDef *const pulse_timer = TIM1;   // Advanced 16-bit timer.
static IRQn_Type const pulse_timer_upd_irq = TIM1_BRK_UP_TRG_COM_IRQn;
static IRQn_Type const pulse_timer_cc_irq  = TIM1_CC_IRQn;

// Ensure the following two consts refer to the same timer.
static TIM_TypeDef *const seq_clock  = TIM2;    // General purpose 32-bit timer.
static IRQn_Type const seq_clock_irq = TIM2_IRQn;

// Ensure the following two consts refer to the same timer.
static TIM_TypeDef *const app_timer  = TIM17;   // General purpose 16-bit timer.
static IRQn_Type const app_timer_irq = TIM17_IRQn;

static BSP bsp = {0};

// Using a couple of functions from STM's infamous HAL.
extern HAL_StatusTypeDef HAL_InitTick(uint32_t);
extern void HAL_IncTick(void);


static void SystemClock_Config(void)
{
    HAL_PWREx_ControlVoltageScaling(PWR_REGULATOR_VOLTAGE_SCALE1);
    PWR->CR1 |= PWR_CR1_DBP;
    while ((PWR->CR1 & PWR_CR1_DBP) == RESET) { /* Wait for write protection to be removed. */ }
    RCC->BDCR = RCC_BDCR_LSEON | RCC_BDCR_LSEDRV_0 | RCC_BDCR_RTCEN;
    while ((RCC->BDCR & RCC_BDCR_LSERDY) == RESET) { /* Wait for LSE to stabilise. */ }
    // TODO Calibrate HSI using LSE and TIM16?

    RCC_OscInitTypeDef RCC_OscInitStruct = {
        .OscillatorType = RCC_OSCILLATORTYPE_HSI,
        .HSIState = RCC_HSI_ON,
        .HSIDiv = RCC_HSI_DIV1,
        .HSICalibrationValue = RCC_HSICALIBRATION_DEFAULT,
        .PLL.PLLState = RCC_PLL_ON,
        .PLL.PLLSource = RCC_PLLSOURCE_HSI,
        .PLL.PLLM = RCC_PLLM_DIV4,
        .PLL.PLLN = 48,
        .PLL.PLLP = RCC_PLLP_DIV12,             // For 16 MHz clock.
        .PLL.PLLQ = RCC_PLLQ_DIV4,              // For 48 MHz clock.
        .PLL.PLLR = RCC_PLLR_DIV3               // For 64 MHz clock.
    };
    HAL_RCC_OscConfig(&RCC_OscInitStruct);

    RCC_ClkInitTypeDef RCC_ClkInitStruct = {
        .ClockType = RCC_CLOCKTYPE_HCLK | RCC_CLOCKTYPE_SYSCLK | RCC_CLOCKTYPE_PCLK1,
        .SYSCLKSource = RCC_SYSCLKSOURCE_PLLCLK,
        .AHBCLKDivider = LL_RCC_SYSCLK_DIV_1,
        .APB1CLKDivider = RCC_HCLK_DIV1
    };
    HAL_RCC_ClockConfig(&RCC_ClkInitStruct, LL_FLASH_LATENCY_2);

    PWR->CR1 &= ~PWR_CR1_DBP;
}


static void enableInterruptWithPrio(IRQn_Type intr, int prio)
{
    NVIC_ClearPendingIRQ(intr);
    NVIC_SetPriority(intr, prio);
    NVIC_EnableIRQ(intr);
}


static void spuriousIRQ(BSP *me)
{
    uint32_t const active_irq_nr = __get_IPSR();
    BSP_logf("%s(%u)\n", __func__, active_irq_nr);
    // TODO Disable the interrupt in question.
}


static void runBootLoader(uint32_t SYS_MEM[])
{
    __set_MSP(SYS_MEM[0]);                      // Set up the bootloader's stackpointer.
    void (*startBootLoader)(void) = (void (*)(void))SYS_MEM[1];
    startBootLoader();                          // This call does not return.
}
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

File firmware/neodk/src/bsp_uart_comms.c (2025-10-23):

/*
 *  bsp_uart_comms.c
 *
 *  NOTICE (do not remove):
 *      This file is part of project NeoDK (https://github.com/Onwrikbaar/NeoDK).
 *      See https://github.com/Onwrikbaar/NeoDK/blob/main/LICENSE.txt for full license details.
 *
 *  Created on: 5 Apr 2025
 *      Author: mark
 *   Copyright  2025 Neostim™
 */

#include "stm32g071xx.h"
#include "stm32g0xx_ll_gpio.h"
#include "stm32g0xx_ll_rcc.h"

#include "bsp_dbg.h"

// This module implements (parts of):
#include "bsp_mao.h"
#include "bsp_comms.h"


#define USART_GPIO_PORT         GPIOA
#define USART2_TX_PIN           LL_GPIO_PIN_2
#define USART2_RX_PIN           LL_GPIO_PIN_3

typedef struct {
    // The following members get set only once.
    Selector rx_sel;
    Selector rx_err_sel;
    void (*tx_callback)(void *, uint8_t *);
    void *tx_target;
    Selector tx_err_sel;
    // The following members may get updated regularly.
    uint8_t nr_of_serial_devices;
} Comms;


static Comms com = {0};


static void initUsartGpio(void)
{
    LL_GPIO_InitTypeDef GPIO_InitStruct = {
        .Mode = LL_GPIO_MODE_ALTERNATE,
        .Alternate = LL_GPIO_AF_1,
        .Pin = USART2_TX_PIN | USART2_RX_PIN
    };
    LL_GPIO_Init(USART_GPIO_PORT, &GPIO_InitStruct);
}


static void initUSART2(uint32_t serial_speed_bps)
{
    USART2->BRR = (uint16_t)((HSI_VALUE + serial_speed_bps / 2) / serial_speed_bps);
    USART2->CR1 |= USART_CR1_UE | USART_CR1_FIFOEN;
}


static void doUartAction(USART_TypeDef *uart, ChannelAction action)
{
    switch (action)
    {
        case CA_RX_CB_ENABLE:
            uart->CR1 |= USART_CR1_RXNEIE_RXFNEIE;
            break;
        case CA_RX_CB_DISABLE:
            uart->CR1 &= ~USART_CR1_RXNEIE_RXFNEIE;
            break;
        case CA_TX_CB_ENABLE:
            uart->CR1 |= USART_CR1_TXEIE_TXFNFIE;
            break;
        case CA_TX_CB_DISABLE:
            uart->CR1 &= ~USART_CR1_TXEIE_TXFNFIE;
            break;
        case CA_OVERRUN_CB_ENABLE:
            break;
        case CA_OVERRUN_CB_DISABLE:
            break;
        case CA_FRAMING_CB_ENABLE:
            break;
        case CA_FRAMING_CB_DISABLE:
            break;
        case CA_CLEAR_ERRORS:
            uart->ICR = USART_ICR_ORECF | USART_ICR_PECF | USART_ICR_NECF | USART_ICR_UDRCF;
            break;
        case CA_CLOSE:
            // TODO Deinit the UART?
            break;
        default:
            BSP_logf("%s(%u): unknown UART action\n", __func__, action);
    }
}

/*
 * Following are the interrupt service routines.
 */

void USART2_IRQHandler(void)
{
    if (USART2->ISR & USART_ISR_RXNE_RXFNE) {
        invokeSelector(&com.rx_sel, USART2->RDR);
    } else if (USART2->ISR & USART_ISR_TXE_TXFNF) {
        if (USART2->CR1 & USART_CR1_TXEIE_TXFNFIE) {
            com.tx_callback(com.tx_target, (uint8_t *)&USART2->TDR);
        }
    } else {
        BSP_logf("%s ISR=0x%x\n", __func__, USART2->ISR);
    }
}

/*
 * Below are the functions implementing this module's interface.
 */

void BSP_initComms(void)
{
    RCC->APBENR1 |= RCC_APBENR1_USART2EN;
    RCC->CCIPR |= LL_RCC_USART2_CLKSOURCE_HSI;
    com.nr_of_serial_devices = 1;               // Device 0 is the SEGGER console.
    initUsartGpio();
    initUSART2(115200UL);
}


DeviceId BSP_openSerialPort(char const *name)
{
    if (com.nr_of_serial_devices > 1) {
        BSP_logf("Can only use one serial port at a time, for now\n");
        return -1;
    }

    BSP_enableUartInterrupt(USART2_IRQn);
    return com.nr_of_serial_devices++;
}


void BSP_registerRxCallback(DeviceId device_id, Selector const *rx_sel, Selector const *rx_err_sel)
{
    M_ASSERT(rx_sel != NULL && rx_err_sel != NULL);
    if (device_id == 1) {
        com.rx_sel = *rx_sel;
        com.rx_err_sel = *rx_err_sel;
        USART2->CR1 |= USART_CR1_RE;            // Enable the receiver.
    }
}


void BSP_registerTxCallback(DeviceId device_id, void (*cb)(void *, uint8_t *), void *target, Selector const *tx_err_sel)
{
    M_ASSERT(cb != NULL && target != NULL);
    if (device_id == 1) {
        com.tx_target = target;
        com.tx_callback = cb;
        com.tx_err_sel = *tx_err_sel;
        USART2->CR1 |= USART_CR1_TE;            // Enable the transmitter.
    }
}


void BSP_doChannelAction(DeviceId device_id, ChannelAction action)
{
    // BSP_logf("%s(%u, %u)\n", __func__, device_id, action);
    switch (device_id)
    {
        case 1:
            doUartAction(USART2, action);
            break;
        default:
            BSP_logf("%s(%u): unknown device id\n", __func__, device_id);
    }
}


int BSP_closeSerialPort(int device_id)
{
    M_ASSERT(device_id == com.nr_of_serial_devices - 1);
    // TODO De-initialise USART2?
    NVIC_DisableIRQ(USART2_IRQn);
    return 0;
}

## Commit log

2023-08-19 Added partial schematic.
2023-08-21 Use triac with 5 mA input current to trigger
2023-09-04 Vcap regulation and 3.3V buck.
2023-09-20 Updated schematic, and more.
2023-10-07 Board place & route done.
2023-10-21 Initial firmware: blinky.
    [neodk_v1.sch]
2023-10-21 Don't track binaries.
2023-11-27 First board.
2023-12-03 Generate pulses.
    [neodk_v1-BOM.csv, neodk_v1.sch]
2023-12-26 More firmware and Eagle board file.
    [neodk_v1.brd, neodk_v1.sch]
2024-01-03 Bug fix and minor stuff.
    [bsp_stm32g071.c, burst.h]
2024-02-27 Prep for serial comms and pulse sequencer.
    [neodk_v1.brd, neodk_v1.sch]
2024-05-07 Updated schematic and board.
    [neodk_v1.brd, neodk_v1.kicad_sch, neodk_v1.sch]
2024-05-09 Add KiCad project. Board not checked!
    [neodk_v1.kicad_pcb, neodk_v1.kicad_sch]
2024-06-03 Added CSV for Toggle routine.
    [Toggle.csv]
2024-08-09 Added feature to switch to bootloader.
    [Intense.csv, Toggle.csv, neodk_v1-BOM.csv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]
2024-08-10 Pics of V1.2 schematic and board layout.
2024-08-11 Catch ADC event in pulsing state.
2024-08-16 Added production files for JLCPCB.
    [neodk_v1.2_top_bom.csv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]
2024-08-19 Always turn on the output stage.
2024-08-20 Reduced quiescent current.
2024-08-23 Add CAD files for enclosure panels.
    [NeoDK-Covers v4.3mf, NeoDK-Covers v4.f3d]
2024-08-23 New CAD files for enclosure panels.
    [NeoDK-Covers v4.3mf, NeoDK-Covers v4.f3d, NeoDK-Covers v5.3mf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]
2024-08-30 Fixed subtle pulse timing bug.
    [bsp_stm32g071.c]
2024-09-10 UI prep.
    [Orgasm_max.csv, Orgasm_min.csv]
2024-09-28 Production files for hardware v1.3.
    [neodk_v1.3.brd, neodk_v1.3.sch, neodk_v1.3_top_bom.csv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]
2024-10-05 Added (default) pattern for mixed impedance electrodes.
2024-10-08 Lower initial voltage and pulse width. Also minor refactoring.
2024-11-20 added battery voltage
2024-11-29 Use fuse that is in stock at JLC.
    [neodk_v1.3_top_bom.csv]
2024-12-07 Fixed pulse width bug.
    [bsp_stm32g071.c]
2025-01-07 Pulse train queue and bug fix.
    [bsp_stm32g071.c]
2025-01-17 Free the 32-bit timer for use by the sequencer.
2025-01-22 Pulse train streaming 🆗
    [NeoDK-Case v9.f3d]
2025-02-22 Bug fixes and minor changes.
    [bsp_stm32g071.c]
2025-02-23 Some Restim adaptations.
    [neodk_v1.3_top_bom.csv]
2025-02-26 Switch triacs earlier.
2025-03-02 Short-pulse triac timing fix.
    [bsp_stm32g071.c]
2025-03-04 Update pulse timer shadow registers shortly before enable.
    [bsp_stm32g071.c, burst.h]
2025-03-21 Updated BoM for availability.
    [neodk_v1.3_top_bom.csv]
2025-04-02 Trigger ADC during each pulse.
2025-05-29 Ensure JLC places the correct FETs.
    [neodk_v1.3_top_bom.csv]
2025-10-23 Only set intensity to default on pattern switch when it is higher.

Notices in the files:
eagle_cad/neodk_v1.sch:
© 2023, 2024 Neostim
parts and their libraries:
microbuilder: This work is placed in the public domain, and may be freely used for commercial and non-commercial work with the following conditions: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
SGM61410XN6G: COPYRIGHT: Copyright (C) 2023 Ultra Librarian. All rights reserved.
